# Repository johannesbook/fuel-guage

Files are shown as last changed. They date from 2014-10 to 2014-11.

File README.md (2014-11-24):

Fuel guage
====

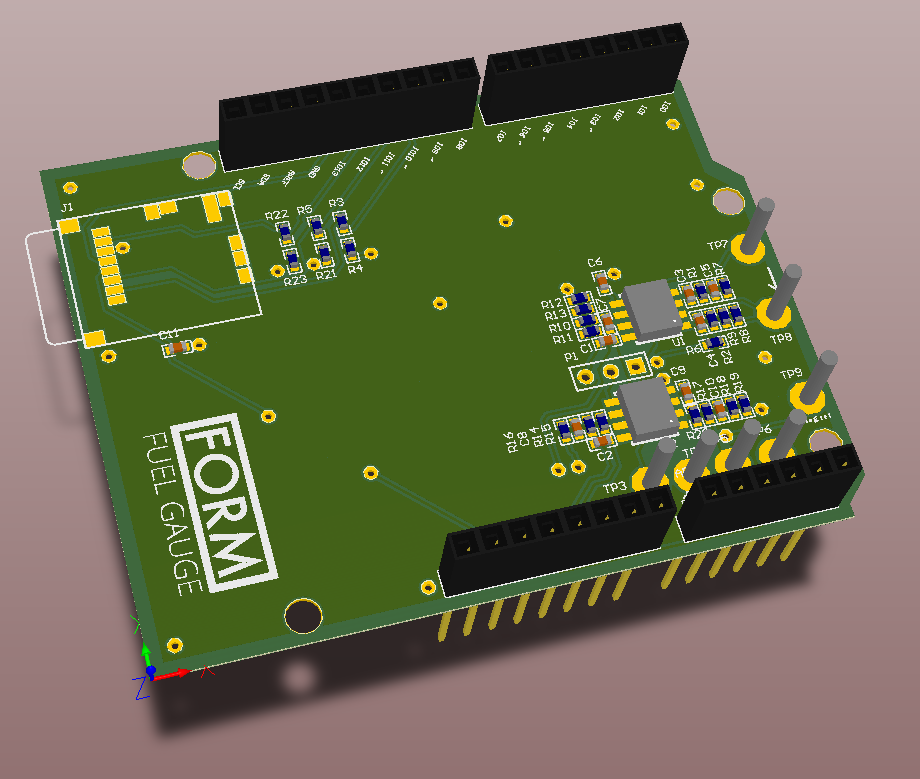
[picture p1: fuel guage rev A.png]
pcb pic


Overview
----

In several projects I have had a need to measure current consumption on battery-powered devices, and there has never been any really good way, no apparatus or tools I found have proven sufficient. 
The typical use case is when you develop a low-power product with a battery that should last for a long time, but with potentially high peak currents, for instance during radio transmission bursts. 
You need to understand how much power your product uses during normal operation in order to optimize the hardware and firmware for lowest power consumption, but there is no way without having high 
resistors in series with your battery, which ruins operation if the device for instance needs to do a radio burst. 

I did this as a simple measurement shield for Arudino Uno, the schematics and layout is in this GitHub repository, together with the Arduino firmware. 

Project status
---
Tested and verified rev B of the schematics, works nicely. A lot of improvements remains (see below), but at least first shot is working now. 

Current features
----
* 1 uA – 1 A measurement range
* No switching series resistors that could interfere with operation, the entire range measured using the same 50 mOhm resistor
* Data output on serial port to PC showing momentary voltage and current

Ideas to future improvements
----
* Display accumulated energy use (mAh or mWh) since measurement start
* Time stamped logging to SD-card 
* Output on display shield for standalone operation
* Make calibration sticky (may not be neccessary to calibrate on every boot) - store in eeprom
* Increase max voltage range by having a high-impedance divider _before_ the unity-gain OP instead of after. (hits maximum input voltage on the OP; VCC-1,5V)

All of those are quite easy, I just didn’t find the time yet. 

Hardware design description
----
The main difficulty here is to amplify say 1 uA over 50 mOhm (that's just 50 nV) to something measureable with reasonable accuracy. I tried using a low noise, very low offset drift OP (offset can always be calibrated for, but offset drift is difficult to manage), the OPA2335. It actually worked reasonably well.

Another pitfall was the series resistor (50 mOhm), which on my PCB turned out to be something like 54 mOhm, due to soldering and pad resistance (4 mOhm is about a mm of copper trace in my case). This was an oversight by me, I should have used a 4-terminal resistor. Instead I just calibrate for the extra 8% in software now, ugly but works. 

Another thing I didn't consider was that the OP's can have negative offsets, which mine turned out to have, which ment the first part of each range was below zero. I therefor added a tiny positive offset to make sure I'm always on the positive side. 

Apart from this the design is quite straight forward, a low-side current measurement resistor (50 mOhm) being amplified using three separate amplifiers and A/D converters, giving three ranges: 
* 0 – 500 uA, 500 nA, theoretical resolution on the Arduino 10-bit A/D
* 500 uA – 20 mA, theoretical resolution 20 uA
* 20 mA – 1 A, theoretical resolution 2 mA

Also a fourth channel measures the voltage through a standard voltage divider. See the schematics on the measurement shield for details. 

All amplifiers have a first order low-pass filter (~10 Hz) to average out any spikes higher than the Arduino sample frequency (100 Hz).  This means that the measured data is 100% correct, but it's impossible to measure the voltage of spikes shorter than 10 Hz (100 ms). 

The rest should be self-explanatory by looking at the schematics. If not just ask me and I'll clarify. 

Hardware revisions
----
There are two revisions, where rev A was done in a hurry and had a few quirks, don't use that one. Rev B has the correct schematics but I never made a PCB from that one, it was easier to build rev B using the rev A board, with some patches. 

Firmware design description
----
The Arduino Uno samples these four channels every 10 ms (exactly!), to make counting energy (mAh) easy. It also chooses the range automatically and outputs the results on a serial port. 

Measured accuracy
----
Note that since three amplifiers are used, the inaccuracy varies across the range – measurements close to the range breaking points are less accurate than other points, which means there is no true general accuracy statement. 
This is what I measured on the first sample: 

(Reference multimeter | DUT | error)  
Range 0:  
 9 uA  |    8 uA  |  <12%  
13 uA  |   11 uA  |  <16%  
19 uA  |   17 uA  |  <11%  
30 uA  |   29 uA  |  <4%  
46 uA  |   46 uA  |  <1%  
89 uA  |   89 uA  |  <1%  
212 uA  |  211 uA  |  <1%  
252 uA  |  249 uA  |  <2%  
325 uA  |  320 uA  |  <2%  
424 uA  |  419 uA  |  <2%  

Range 1:  
505 uA  |  516 uA  |  <3%  
613 uA  |  626 uA  |  <3%  
917 uA  |  921 uA  |  <1%  
1197 uA |  1198 uA |  <1%  
1704 uA |  1714 uA |  <1%  
11,3 mA |  11,1 mA |  <2%  

Range 2:  
20,8 mA |  21 mA   |  <1%  
51,4 mA |  52 mA   |  <2%  
96,0 mA |  95 mA   |  <2%  
235 mA  |  233 mA  |  <1%  
0,53 A  |  514 mA  |  <3%  
0,71 A  |  697 mA  |  <2%  
0,88 A  |  873 mA  |  <1%  

Voltage:  
285 mV  |   275 mV | <4%  
1,726 v |  1755 mV | <2%  
2,327 V |  2375 mV | <1%  
3,34 V  |  3415 mV | <3%  
3,60 V  |  3680 mV | <3%  

So in general, better than 4% accuracy can be expected in average. Accuracy is worse in the lower area of each range (due to limited resolution), and at some points it might theoretically be worse than 4%.

Accuracy on very low currents is bad, don't know why yet. Could just as well be my reference multimeter, I will double check this when I have a chance. 

Other tests carried out
----
* step response, made sure LP filters on all three ranges has time constant well above the 10 ms sampling rate. 
* tested that variations in supply voltage does not affect readings

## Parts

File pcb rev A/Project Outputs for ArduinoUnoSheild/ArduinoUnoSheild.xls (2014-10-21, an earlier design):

Comment | Description | Designator | Footprint | LibRef | Quantity | Value
AD |  | AD | Header 6x1 8.5mm | AD | 1
Header 3 | Header, 3-Pin | P1 | HDR1X3 | Header 3 | 1
IOH |  | IOH | Header 10x1 8.5mm | IOH | 1
IOL |  | IOL | Header 8x1 8.5mm | IOL | 1
MicroSD |  | J1 | micro SD | MicroSD | 1
OPA2335 | Dual and Quad 75 MHz GBW Rail-to-Rail I/O Operational | U1, U2 | SO8 | 104 | 2
POWER_UNO |  | POWER | Header 8x1 8.5mm | POWER_UNO | 1
TESTPOINT_1.6MM | Testpoint | TP3, TP4, TP5, TP6, TP7, TP8, TP9 | TESTPOINT_1.6MM | 203 | 7
RES_STANDARD | Resistor 0603 SMD | R1, R2, R3, R4, R5, R6, R7, R8, R9, R10, R11, R12, R13, R14, R15, R16, R17, R18, R19, R20, R21, R22, R23 | RES0603 | 276 | 23 | 0R, 1M, 4k7, 10k, 4k7, 1M, 50 mOhm, 4k7, 47R, 1M, 75k, DNP, 1k, 430k, 430k, 1M, 910k, DNP, 1k, 22k, 10k, 4k7, 10k
CAP0603 | Ceramic Capacitor SMD 0603 | C1, C2, C3, C4, C5, C6, C7, C8, C9, C10, C11 | 0603CAP | 185 | 11 | 100n, 100n, DNP, 10n, DNP, DNP, 10n, 10n, DNP, 1u, 100n

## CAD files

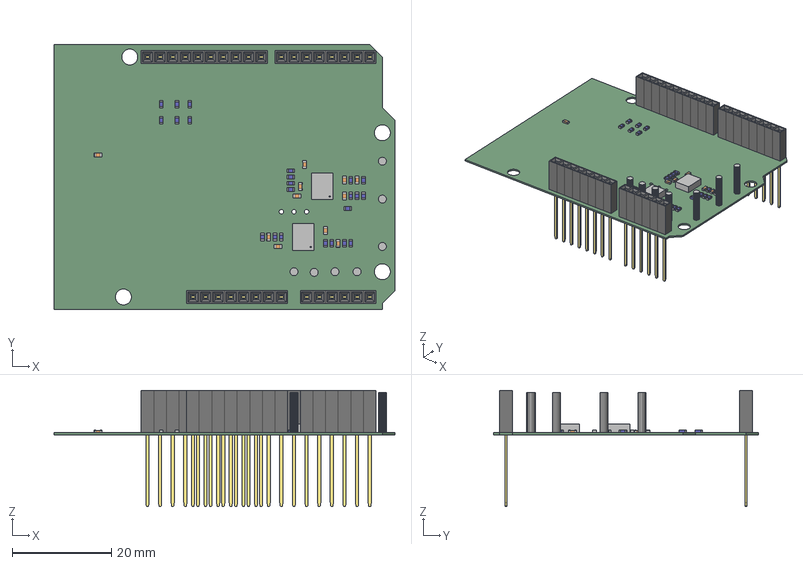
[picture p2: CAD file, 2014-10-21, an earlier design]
pcb rev A/test.step
68.6 x 53.3 x 23.4 mm
Board
Extruded x 80
User_Library-Chip_Cap_MLCC_0603_(1608) x 11
SIL_Socket_Body x 32
SIL_SocketPin x 32

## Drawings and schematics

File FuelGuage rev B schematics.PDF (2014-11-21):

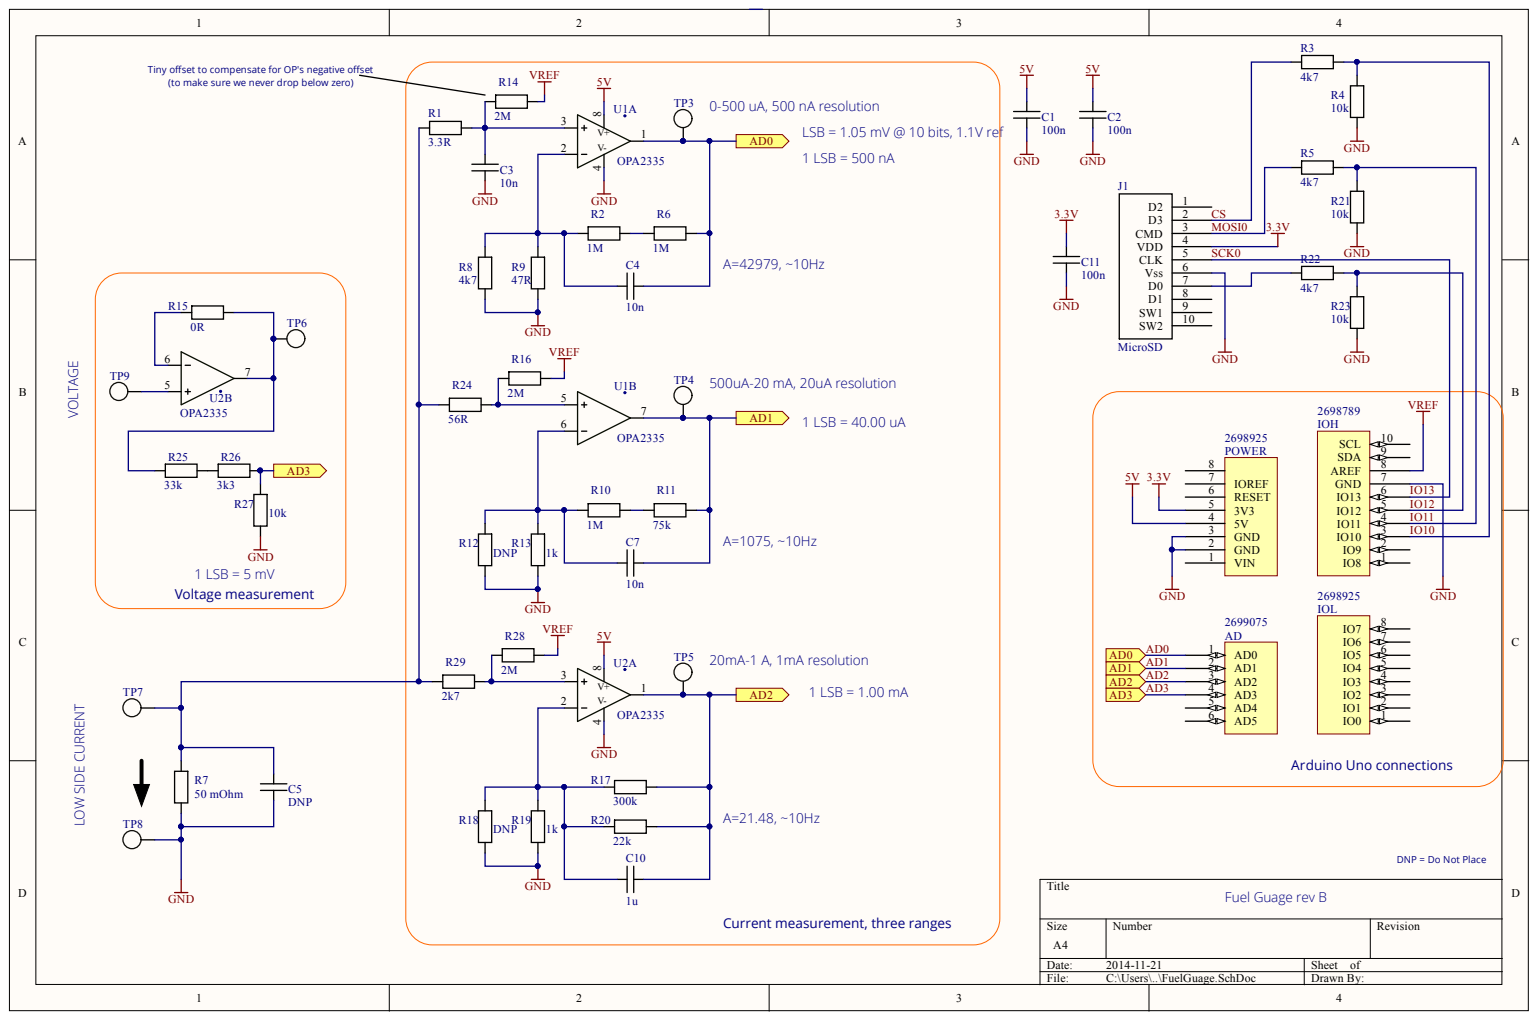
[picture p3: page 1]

Tiny offset to compensate for OP's negative offset
(to make sure we never drop below zero)

LSB = 1.05 mV @ 10 bits, 1.1V ref

MOSI0 3.3V

DNP = Do Not Place

Current measurement, three ranges

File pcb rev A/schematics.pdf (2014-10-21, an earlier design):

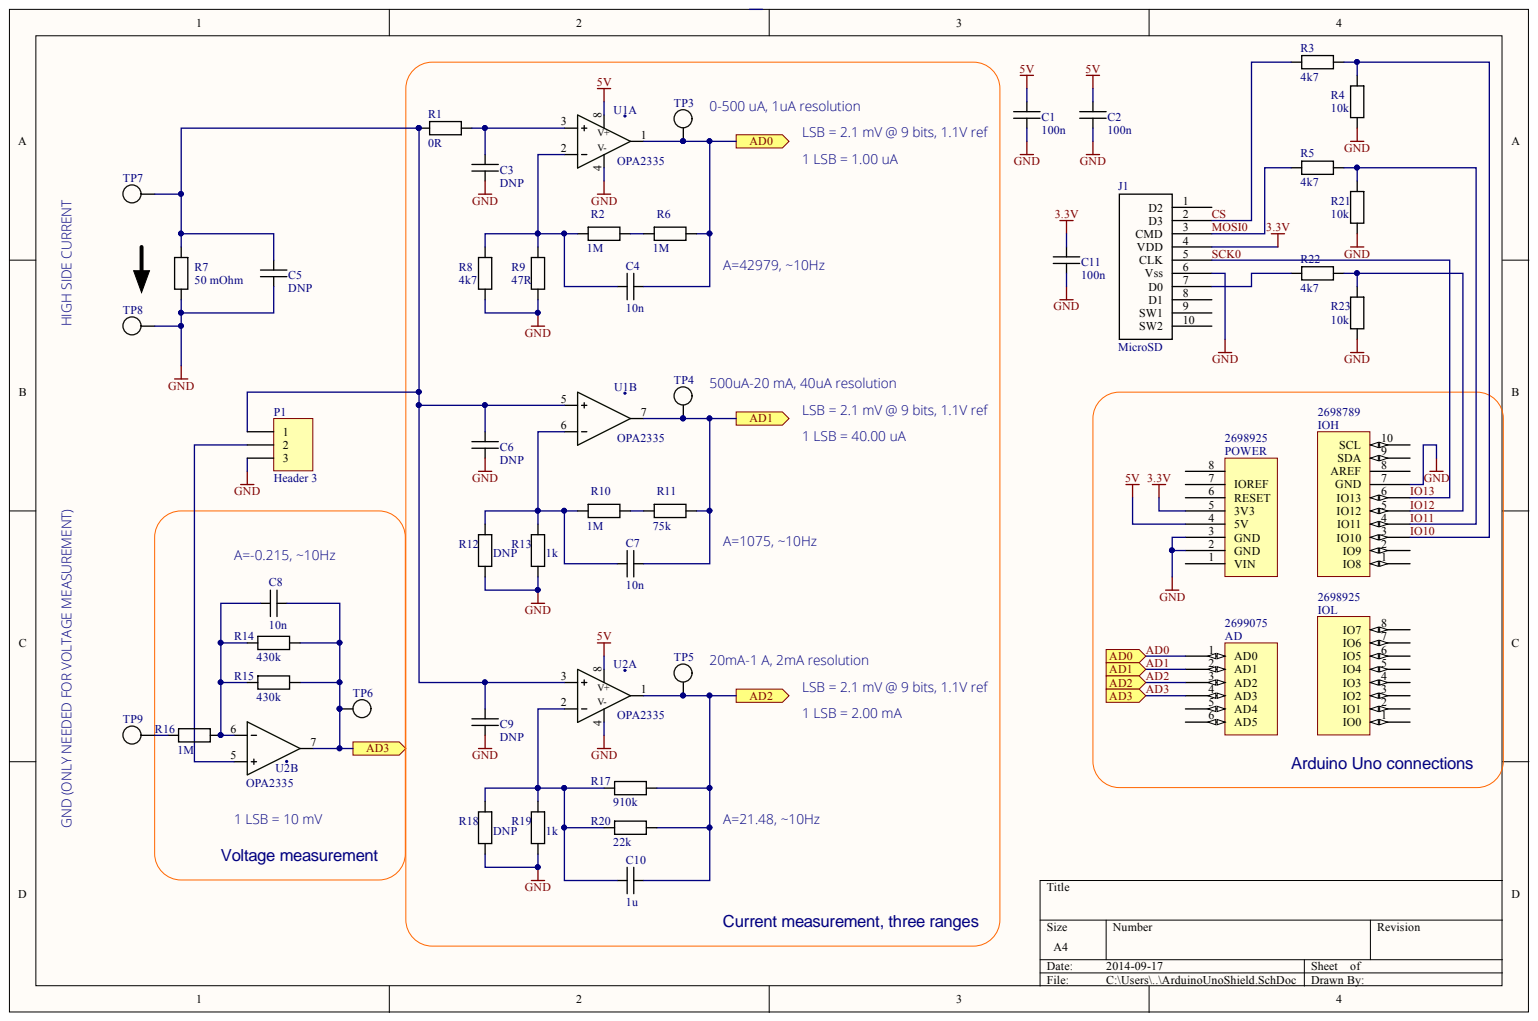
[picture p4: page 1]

HIGH SIDE CURRENT GND (ONLY NEEDED FOR VOLTAGE MEASUREMENT)

P1Header 3 123

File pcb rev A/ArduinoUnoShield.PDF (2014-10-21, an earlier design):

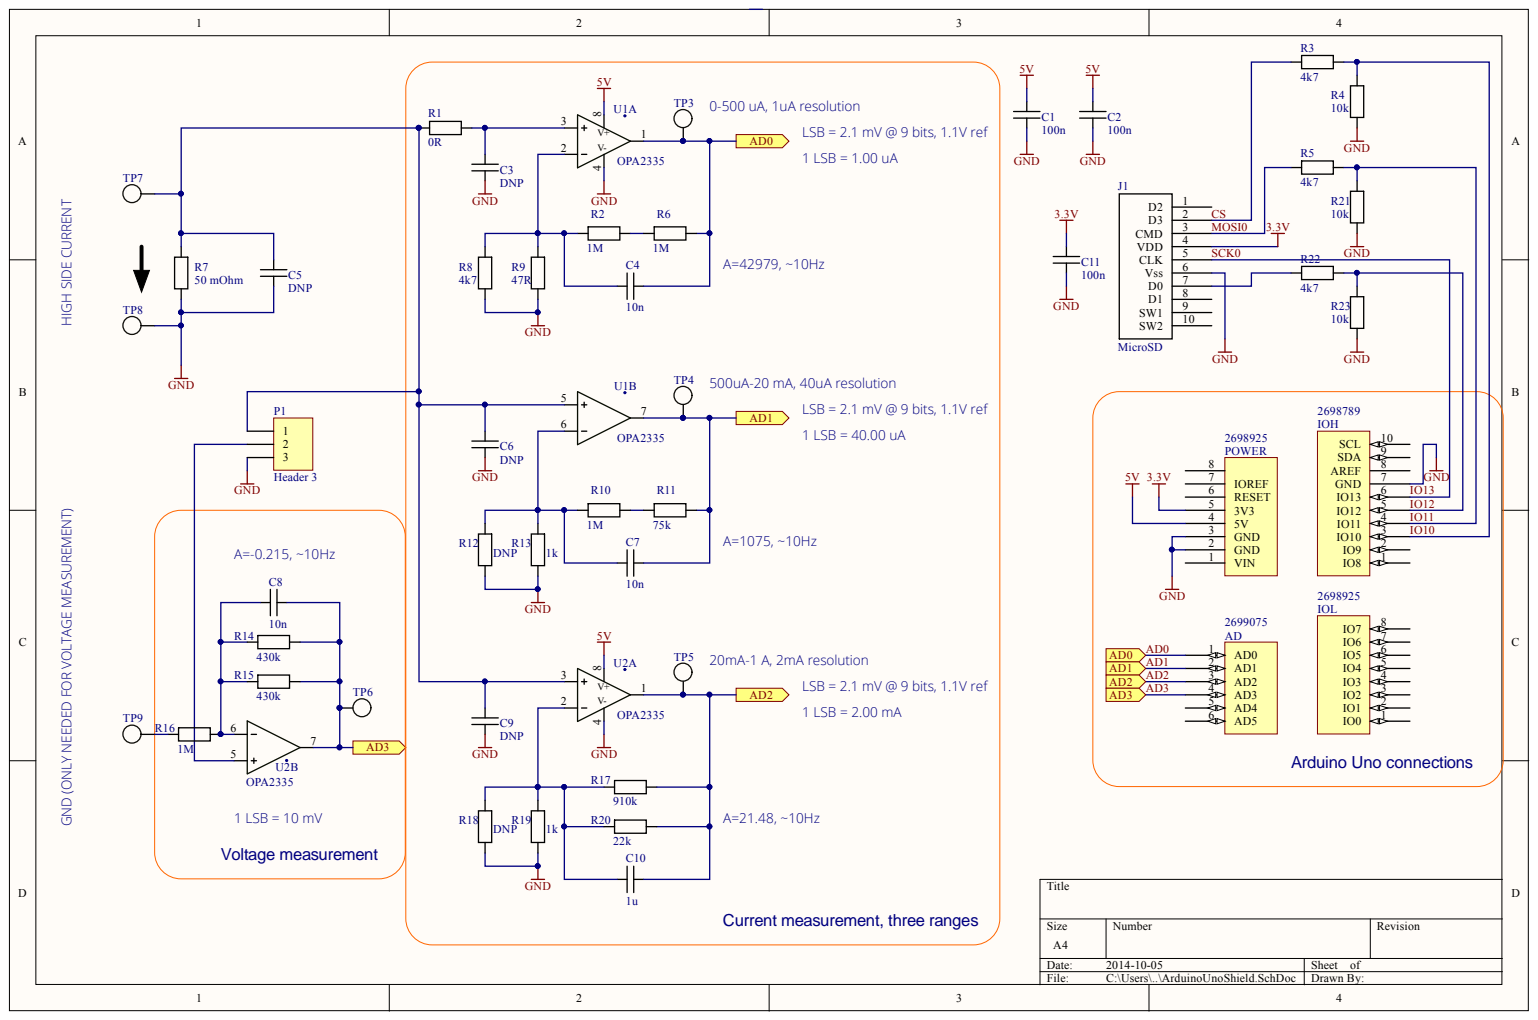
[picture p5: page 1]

LSB = 2.1 mV @ 9 bits, 1.1V ref

HIGH SIDE CURRENT GND (ONLY NEEDED FOR VOLTAGE MEASUREMENT)

MOSI0 3.3V

Current measurement, three ranges

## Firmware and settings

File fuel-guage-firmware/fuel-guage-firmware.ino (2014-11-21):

/*
 Johannes Book 2014
 Fuel guage tool, made for measuring low currents and count energy, 1uA -> 1A.  

*/

signed long rangeZero[3] = {69,27,26}; //default calibration values
signed long currentNow, voltageNow, accCurrent, time; 
signed int range[3], voltage, usedRange;
String unit;

void setup() {
  cli(); //turn off interrupts
  Serial.begin(115200);
  analogReference(INTERNAL); //using 1.1V internal voltage ref to make this independent of supply voltage variations
  analogRead(A0); //to kick A/D in the butt, otherwise the reference change won't happen until later
  pinMode(2,OUTPUT); //debug pin
  time = 0;
  
  //setup interrupts
  TCCR1A = 0;
  TCCR1B = 0;
  TCNT1  = 0;
  OCR1A = 156;
  TCCR1B |= (1 << WGM12); 
  TCCR1B |= (1 << CS12) | (1 << CS10);  //1024 prescaler
  TIMSK1 |= (1 << OCIE1A);   // enable timer compare interrupt  
  sei(); //allow interrupts
}

/***** Calibrate *****
To subtract the OP offset value, which varies with temperature and between units
*********************/
void Calibrate() {
  unsigned int c;
  rangeZero[0] = 0;
  rangeZero[1] = 0;
  rangeZero[2] = 0;
  
  Serial.println("Calibrating, please disconnect all three pins now. Let me know when done.");
  while(Serial.available()==0);
  Serial.print("Thanks. Give me a second... ");  
  for (c=0; c<1000; c++) {
    delayMicroseconds(7000); //since delay() messes up the timer interrupts we use for other things
  }
  for (c=0; c<2048; c++) { //some averaging
    rangeZero[0] += analogRead(A0);
    delay(2); //allow AD to cool down
    rangeZero[1] += analogRead(A1);
    delay(2); //allow AD to cool down
    rangeZero[2] += analogRead(A2);
    delay(2); //allow AD to cool down
  }
  rangeZero[0] = rangeZero[0] >> 11;
  rangeZero[1] = rangeZero[1] >> 11;
  rangeZero[2] = rangeZero[2] >> 11;
  Serial.print("offset values are: ");
  Serial.print(rangeZero[0]);
  Serial.print(", ");
  Serial.print(rangeZero[1]);
  Serial.print(", ");
  Serial.print(rangeZero[2]);
  Serial.println(".");
  for (c=0; c<1000; c++) { //delay to allow reading the last message
    delayMicroseconds(1000); //since delay() messes up the timer interrupts we use for other things
  }
  time = 0; //reset timer when calibrating
}  

/****** ISR ******
sample and accumulate exactly every 10 ms (100 Hz) (which is faster than hw LP filter, which means we won't miss anything in between samples)
Note: After adding stuff here, make sure this routine never closes in on 10ms (will starve main loop). If it exceeds 10 ms, things will break. 
*****************/
ISR(TIMER1_COMPA_vect){ //
  digitalWrite(2,HIGH);
  range[0] = analogRead(A0);
  range[1] = analogRead(A1);
  range[2] = analogRead(A2);
  if (range[0] < 1023) {
    currentNow = (range[0] - rangeZero[0]) / 2; //1 bit <=> 500 nA
    unit = "uA";
    usedRange = 0;
  } else if (range[1] < 1023) {
    currentNow = (range[1] - rangeZero[1]) * 20; //1 bit <=> 20 uA
    unit = "uA";
    usedRange = 1;
  } else {
    currentNow = (range[2] - rangeZero[2]); //1 bit <=> 1 mA
    unit = "mA";
    usedRange = 2;
  }  
  currentNow = currentNow * 118;  // 118/128 ~= -8%, which seems to be the trace resistance adding to the 50 mOhm resistor
  currentNow = currentNow >> 7; 
 
  voltage = analogRead(A3);
  voltageNow = (voltage * 5);
  
  time += 1; //each tick equals 10 ms
  
  digitalWrite(2,LOW);  
}

/****** MAIN ******
only printouts, maths and calibration, no sampling allowed here
*****************/
void loop() {

  int command, seconds, minutes, hours;
  #define TICS_PER_HOUR (360000UL)  
  #define TICS_PER_MINUTE (6000UL)
  #define TICS_PER_SECOND (100UL)

  while(1) {
    //Time:
    seconds = (time / TICS_PER_SECOND) % 60;
    minutes = (time / TICS_PER_MINUTE) % 60;
    hours = time / TICS_PER_HOUR;
    if (hours < 10) {
      Serial.print("0");
    }
    Serial.print(hours); 
    Serial.print(":");
    if (minutes < 10) {
      Serial.print("0");
    }
    Serial.print(minutes); 
    Serial.print(":");
    if (seconds < 10) {
      Serial.print("0");
    }
    Serial.print(seconds); 
    Serial.print(" | ");

    //Momentous values
    Serial.print(currentNow);
    Serial.print(" ");
    Serial.print(unit);
    Serial.print(" | ");
    Serial.print(voltageNow); 
    Serial.print(" mV");
    Serial.print(" | ");
    
    //Accumulated values
    
    //debug prints    
    Serial.print("   debug:");
    if (usedRange == 0) {
      Serial.print("*");
    }
    Serial.print(range[0]);
    Serial.print(" | ");
    if (usedRange == 1) {
      Serial.print("*");
    }
    Serial.print(range[1]);
    Serial.print(" | ");
    if (usedRange == 2) {
      Serial.print("*");
    }
    Serial.print(range[2]);
    Serial.print(" | ");
    Serial.print(voltage);
    Serial.print(" | ");
    Serial.println(time);
    
    if(Serial.available()!=0) {
      command = Serial.read();
      if (command == 0x63) { //0x63 = 'c'
        Calibrate();
      }
    }
    delay(200);
  }
}

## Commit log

2014-11-21 Update README.md
    added note about resistor accuracy and OP offset
2014-11-21 added picture of pcb
2014-11-21 Added rev B of design
    rev B which is rev A + bug fixes. No PCB done yet, just schematics.
    [FuelGuage.SchDoc]
2014-11-21 renamed folder
    pcb -> pcb rev A
    [ArduinoUnoSheild.PrjPcb, ArduinoUnoSheild.xls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]
